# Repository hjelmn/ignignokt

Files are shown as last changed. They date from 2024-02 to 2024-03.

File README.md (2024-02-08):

This project contains all the files from my recreation of the Ignignokt LED sign. Included in this repository are the current Kicad files.

The board is roughly based on the data available at:

https://hackaday.io/project/183827-reverse-engineering-the-mooninite-led-panels/details

with minor modifications (there could be errors-- if you find some please post a PR with the fix):

 - Added a barrel power input to support an external power supply. Added a circuit to disable the batter if an external power supply is connected. This circuit uses a P-channel MOSFET which closes the Batt+ when a voltage is detected on Vcc.
 - Added a battery pack connector and pads to solder on a battery.

TODO:

 - Code for the microcontroller.
 - Err

The current version of the board costs roughly $85 to produce with LEDs from China and parts sourced from the US.

To use this project download kicad and open the project.

The license for all of these files is GPLv3.

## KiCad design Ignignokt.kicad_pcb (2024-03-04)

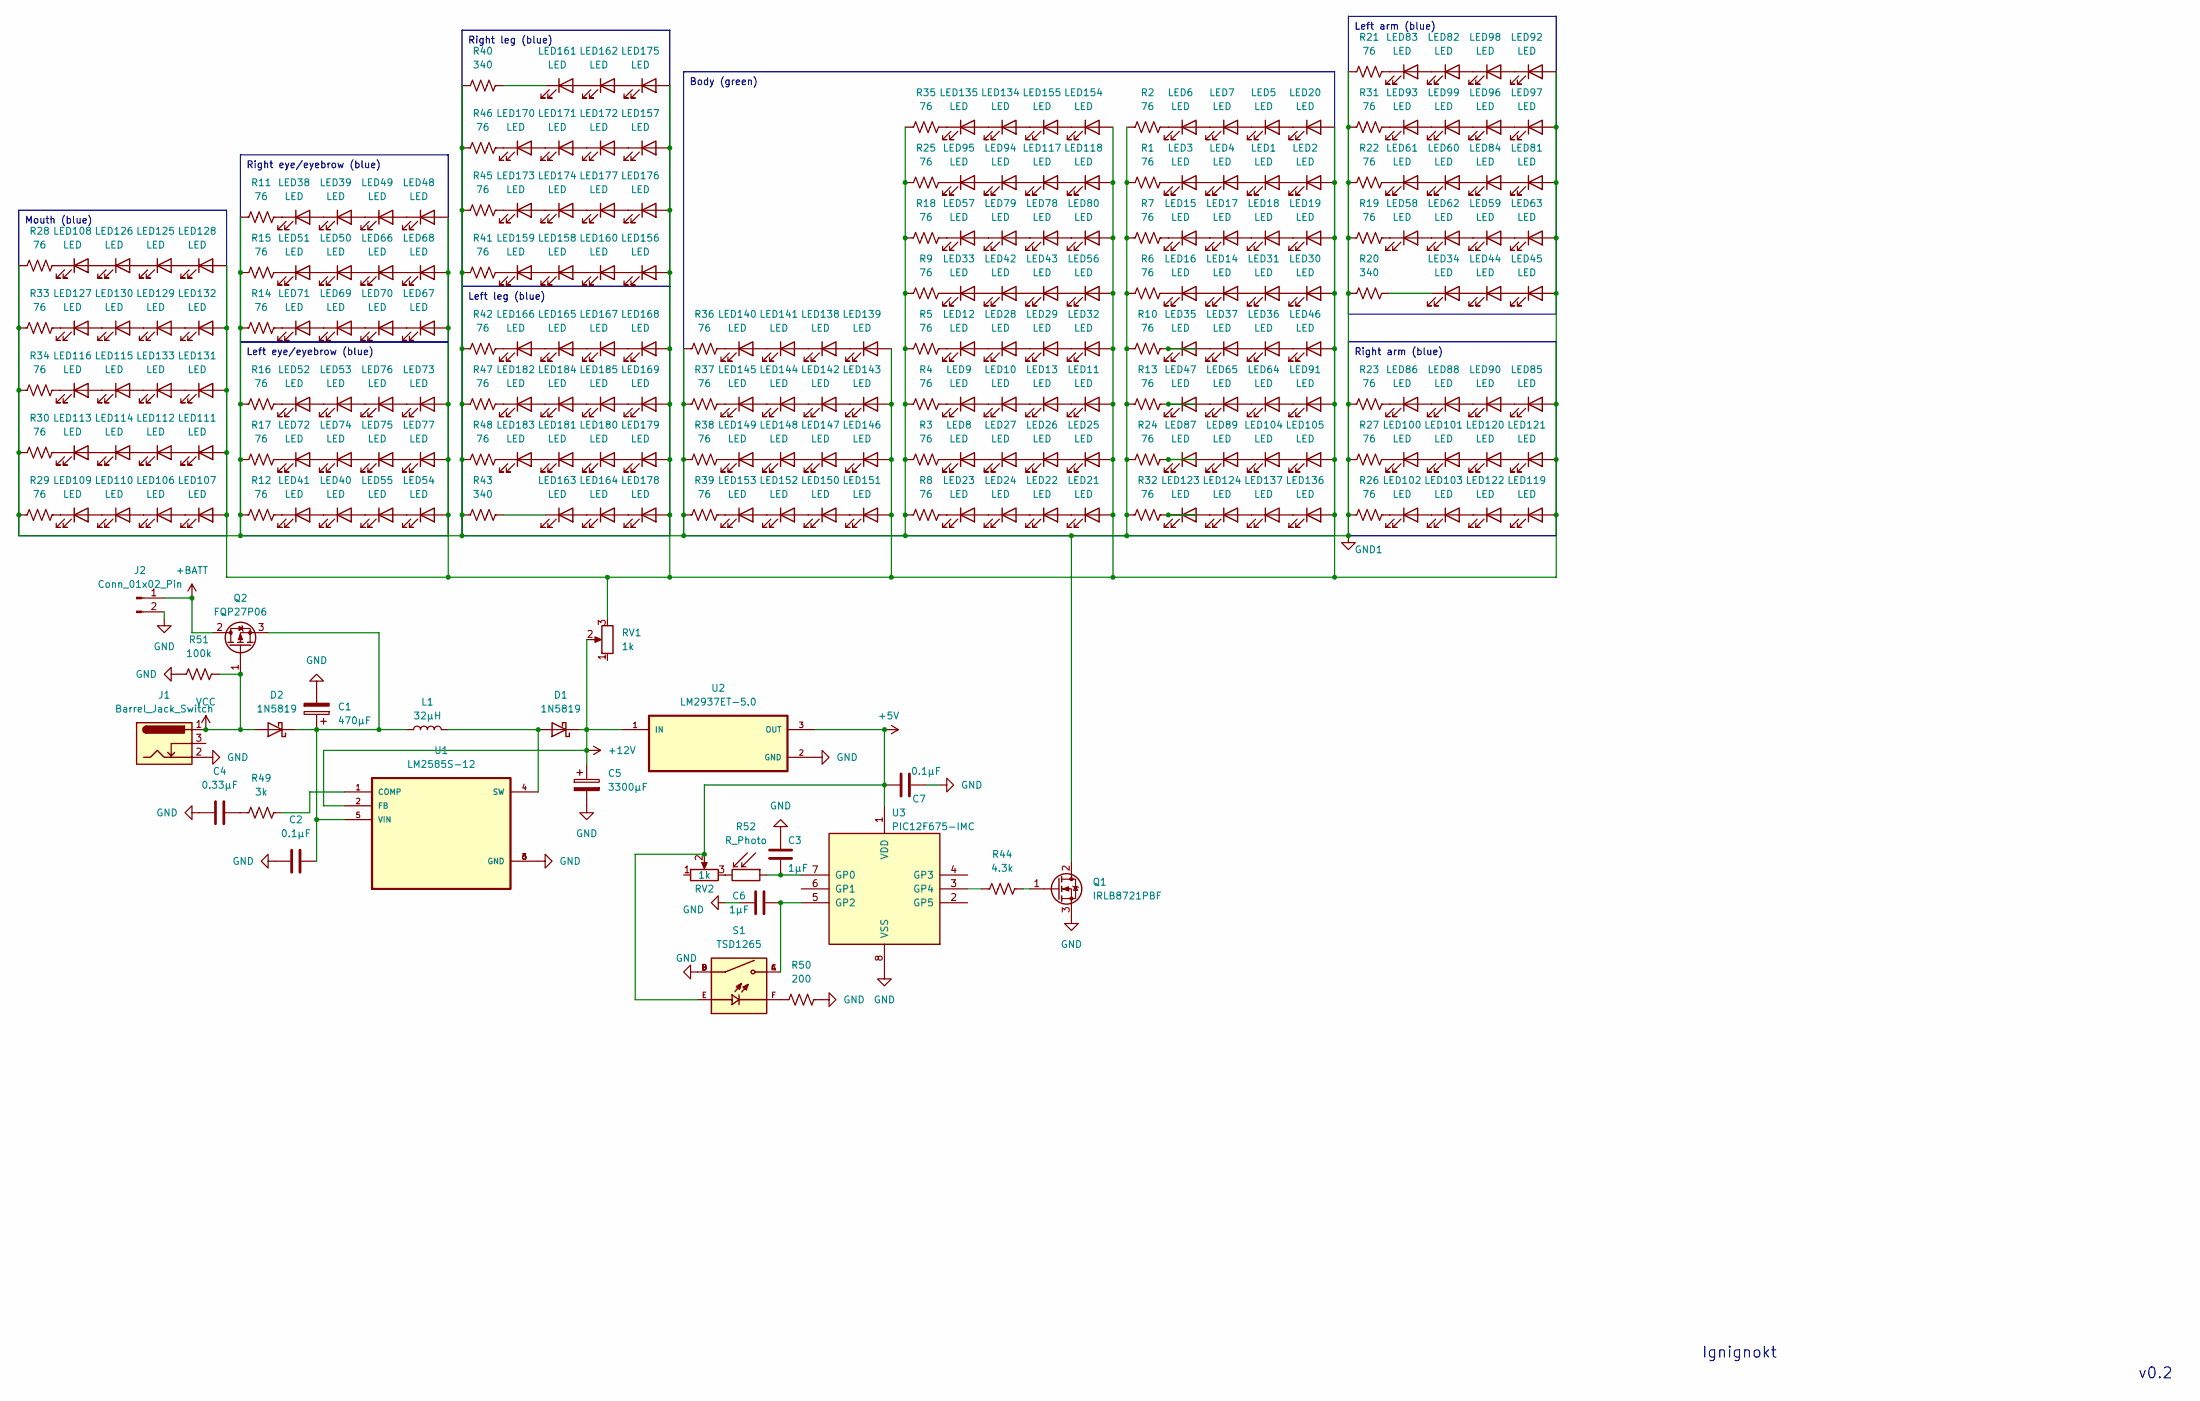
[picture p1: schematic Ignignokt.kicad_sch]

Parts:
C1: 470µF; CP_Radial_D10.0mm_P5.00mm
C2, C7: 0.1µF; C_Disc_D3.0mm_W2.0mm_P2.50mm
C3, C6: 1µF; C_Disc_D5.1mm_W3.2mm_P5.00mm
C4: 0.33µF; C_Disc_D5.1mm_W3.2mm_P5.00mm
C5: 3300µF; CP_Radial_D18.0mm_P7.50mm
D1, D2: 1N5819; D_DO-41_SOD81_P10.16mm_Horizontal
J1: Barrel_Jack_Switch; BarrelJack_Wuerth_6941xx301002
J2: Conn_01x02_Pin; JST_EH_B2B-EH-A_1x02_P2.50mm_Vertical
L1: 32µH; L_CommonMode_Toroid_Vertical_L24.0mm_W16.3mm_Px10.16mm_Py20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
LED1, LED2, LED3, LED4, LED5, LED6, LED7, LED8, LED9, LED10, LED11, LED12, LED13, LED14, LED15, LED16, LED17, LED18, LED19, LED20, LED21, LED22, LED23, LED24, LED25, LED26, LED27, LED28, LED29, LED30, LED31, LED32, LED33, LED34, LED35, LED36, LED37, LED38, LED39, LED40, LED41, LED42, LED43, LED44, LED45, LED46, LED47, LED48, LED49, LED50, LED51, LED52, LED53, LED54, LED55, LED56, LED57, LED58, LED59, LED60, LED61, LED62, LED63, LED64, LED65, LED66, LED67, LED68, LED69, LED70, LED71, LED72, LED73, LED74, LED75, LED76, LED77, LED78, LED79, LED80, LED81, LED82, LED83, LED84, LED85, LED86, LED87, LED88, LED89, LED90, LED91, LED92, LED93, LED94, LED95, LED96, LED97, LED98, LED99, LED100, LED101, LED102, LED103, LED104, LED105, LED106, LED107, LED108, LED109, LED110, LED111, LED112, LED113, LED114, LED115, LED116, LED117, LED118, LED119, LED120, LED121, LED122, LED123, LED124, LED125, LED126, LED127, LED128, LED129, LED130, LED131, LED132, LED133, LED134, LED135, LED136, LED137, LED138, LED139, LED140, LED141, LED142, LED143, LED144, LED145, LED146, LED147, LED148, LED149, LED150, LED151, LED152, LED153, LED154, LED155, LED156, LED157, LED158, LED159, LED160, LED161, LED162, LED163, LED164, LED165, LED166, LED167, LED168, LED169, LED170, LED171, LED172, LED173, LED174, LED175, LED176, LED177, LED178, LED179, LED180, LED181, LED182, LED183, LED184, LED185: LED; LED_D10.0mm
Q1: IRLB8721PBF; TO-220-3_Horizontal_TabDown
Q2: FQP27P06; TO-220-3_Horizontal_TabDown
R1, R2, R3, R4, R5, R6, R7, R8, R9, R10, R11, R12, R13, R14, R15, R16, R17, R18, R19, R21, R22, R23, R24, R25, R26, R27, R28, R29, R30, R31, R32, R33, R34, R35, R36, R37, R38, R39, R41, R42, R45, R46, R47, R48: 76; R_Axial_DIN0207_L6.3mm_D2.5mm_P10.16mm_Horizontal
R20, R40, R43: 340; R_Axial_DIN0207_L6.3mm_D2.5mm_P10.16mm_Horizontal
R44: 4.3k; R_Axial_DIN0207_L6.3mm_D2.5mm_P10.16mm_Horizontal
R49: 3k; R_Axial_DIN0207_L6.3mm_D2.5mm_P10.16mm_Horizontal
R50: 200; R_Axial_DIN0207_L6.3mm_D2.5mm_P10.16mm_Horizontal
R51: 100k; R_Axial_DIN0207_L6.3mm_D2.5mm_P10.16mm_Horizontal
R52: R_Photo; R_LDR_D6.4mm_P3.4mm_Vertical
RV1, RV2: 1k; Potentiometer_Bourns_3299W_Vertical; Part 3299W-1-103LF
S1: TSD1265; SW_TSD1265; PARTREV N/A
U1: LM2585S-12; VREG_TPS79625KTTR - LM2585S-12
U2: LM2937ET-5.0; TO-220-3_Horizontal_TabDown
U3: PIC12F675-IMC; DIP-8_W7.62mm

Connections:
+5V: C7.2, RV2.2, S1.E, U2.3 (OUT), U3.1 (VDD)
+12V: C5.1, D1.1 (K), RV1.2, U1.2 (FB), U2.1 (IN)
+BATT: J2.1, Q2.2 (D)
GND: C1.2, C2.2, C3.1, C4.2, C5.2, C6.2, C7.1, J1.2, J2.2, Q1.3 (S), R50.1, R51.2, S1.B, S1.D, U1.3 (GND), U1.6 (GND), U2.2 (GND), U3.8 (VSS)
GND1: Q1.2 (D), R1.2, R2.2, R3.2, R4.2, R5.2, R6.2, R7.2, R8.2, R9.2, R10.2, R11.2, R12.2, R13.2, R14.2, R15.2, R16.2, R17.2, R18.2, R19.2, R20.2, R21.2, R22.2, R23.2, R24.2, R25.2, R26.2, R27.2, R28.2, R29.2, R30.2, R31.2, R32.2, R33.2, R34.2, R35.2, R36.2, R37.2, R38.2, R39.2, R40.2, R41.2, R42.2, R43.2, R45.2, R46.2, R47.2, R48.2
unnamed: C4.1, R49.2
unnamed: D1.2 (A), L1.2, U1.4 (SW)
unnamed: C1.1, C2.1, D2.1 (K), L1.1, Q2.3 (S), U1.5 (VIN)
unnamed: LED1.2 (A), LED2.1 (K)
unnamed: LED1.1 (K), LED4.2 (A)
unnamed: LED3.2 (A), LED4.1 (K)
unnamed: LED3.1 (K), R1.1
unnamed: LED5.1 (K), LED7.2 (A)
unnamed: LED6.2 (A), LED7.1 (K)
unnamed: LED6.1 (K), R2.1
unnamed: LED8.1 (K), R3.1
unnamed: LED9.1 (K), R4.1
unnamed: LED10.2 (A), LED13.1 (K)
unnamed: LED9.2 (A), LED10.1 (K)
unnamed: LED11.1 (K), LED13.2 (A)
unnamed: LED12.2 (A), LED28.1 (K)
unnamed: LED12.1 (K), R5.1
unnamed: LED14.2 (A), LED31.1 (K)
unnamed: LED14.1 (K), LED16.2 (A)
unnamed: LED15.2 (A), LED17.1 (K)
unnamed: LED15.1 (K), R7.1
unnamed: LED16.1 (K), R6.1
unnamed: LED17.2 (A), LED18.1 (K)
unnamed: LED18.2 (A), LED19.1 (K)
unnamed: LED5.2 (A), LED20.1 (K)
unnamed: LED21.1 (K), LED22.2 (A)
unnamed: LED22.1 (K), LED24.2 (A)
unnamed: LED23.2 (A), LED24.1 (K)
unnamed: LED23.1 (K), R8.1
unnamed: LED25.1 (K), LED26.2 (A)
unnamed: LED26.1 (K), LED27.2 (A)
unnamed: LED8.2 (A), LED27.1 (K)
unnamed: LED28.2 (A), LED29.1 (K)
unnamed: LED29.2 (A), LED32.1 (K)
unnamed: LED30.1 (K), LED31.2 (A)
unnamed: LED33.2 (A), LED42.1 (K)
unnamed: LED33.1 (K), R9.1
unnamed: LED34.2 (A), LED44.1 (K)
unnamed: LED34.1 (K), R20.1
unnamed: LED35.2 (A), LED37.1 (K)
unnamed: LED35.1 (K), R10.1
unnamed: LED36.2 (A), LED46.1 (K)
unnamed: LED36.1 (K), LED37.2 (A)
unnamed: LED38.2 (A), LED39.1 (K)
unnamed: LED38.1 (K), R11.1
unnamed: LED39.2 (A), LED49.1 (K)
unnamed: LED40.2 (A), LED55.1 (K)
unnamed: LED40.1 (K), LED41.2 (A)
unnamed: LED41.1 (K), R12.1
unnamed: LED42.2 (A), LED43.1 (K)
unnamed: LED43.2 (A), LED56.1 (K)
unnamed: LED44.2 (A), LED45.1 (K)
unnamed: LED47.2 (A), LED65.1 (K)
unnamed: LED47.1 (K), R13.1
unnamed: LED48.1 (K), LED49.2 (A)
unnamed: LED50.2 (A), LED66.1 (K)
unnamed: LED50.1 (K), LED51.2 (A)
unnamed: LED51.1 (K), R15.1
unnamed: LED52.2 (A), LED53.1 (K)
unnamed: LED52.1 (K), R16.1
unnamed: LED53.2 (A), LED76.1 (K)
unnamed: LED54.1 (K), LED55.2 (A)
unnamed: LED57.2 (A), LED79.1 (K)
unnamed: LED57.1 (K), R18.1
unnamed: LED58.2 (A), LED62.1 (K)
unnamed: LED58.1 (K), R19.1
unnamed: LED59.2 (A), LED63.1 (K)
unnamed: LED59.1 (K), LED62.2 (A)
unnamed: LED60.2 (A), LED84.1 (K)
unnamed: LED60.1 (K), LED61.2 (A)
unnamed: LED61.1 (K), R22.1
unnamed: LED64.2 (A), LED91.1 (K)
unnamed: LED64.1 (K), LED65.2 (A)
unnamed: LED66.2 (A), LED68.1 (K)
unnamed: LED67.1 (K), LED70.2 (A)
unnamed: LED69.2 (A), LED70.1 (K)
unnamed: LED69.1 (K), LED71.2 (A)
unnamed: LED71.1 (K), R14.1
unnamed: LED72.2 (A), LED74.1 (K)
unnamed: LED72.1 (K), R17.1
unnamed: LED73.1 (K), LED76.2 (A)
unnamed: LED74.2 (A), LED75.1 (K)
unnamed: LED75.2 (A), LED77.1 (K)
unnamed: LED78.2 (A), LED80.1 (K)
unnamed: LED78.1 (K), LED79.2 (A)
unnamed: LED81.1 (K), LED84.2 (A)
unnamed: LED82.2 (A), LED98.1 (K)
unnamed: LED82.1 (K), LED83.2 (A)
unnamed: LED83.1 (K), R21.1
unnamed: LED85.1 (K), LED90.2 (A)
unnamed: LED86.2 (A), LED88.1 (K)
unnamed: LED86.1 (K), R23.1
unnamed: LED87.2 (A), LED89.1 (K)
unnamed: LED87.1 (K), R24.1
unnamed: LED88.2 (A), LED90.1 (K)
unnamed: LED92.1 (K), LED98.2 (A)
unnamed: LED93.2 (A), LED99.1 (K)
unnamed: LED93.1 (K), R31.1
unnamed: LED94.1 (K), LED95.2 (A)
unnamed: LED95.1 (K), R25.1
unnamed: LED96.2 (A), LED97.1 (K)
unnamed: LED96.1 (K), LED99.2 (A)
unnamed: LED100.2 (A), LED101.1 (K)
unnamed: LED100.1 (K), R27.1
unnamed: LED101.2 (A), LED120.1 (K)
unnamed: LED102.2 (A), LED103.1 (K)
unnamed: LED102.1 (K), R26.1
unnamed: LED103.2 (A), LED122.1 (K)
unnamed: LED104.2 (A), LED105.1 (K)
unnamed: LED89.2 (A), LED104.1 (K)
unnamed: LED2.2 (A), LED11.2 (A), LED19.2 (A), LED20.2 (A), LED21.2 (A), LED25.2 (A), LED30.2 (A), LED32.2 (A), LED45.2 (A), LED46.2 (A), LED48.2 (A), LED54.2 (A), LED56.2 (A), LED63.2 (A), LED67.2 (A), LED68.2 (A), LED73.2 (A), LED77.2 (A), LED80.2 (A), LED81.2 (A), LED85.2 (A), LED91.2 (A), LED92.2 (A), LED97.2 (A), LED105.2 (A), LED107.2 (A), LED111.2 (A), LED118.2 (A), LED119.2 (A), LED121.2 (A), LED128.2 (A), LED131.2 (A), LED132.2 (A), LED136.2 (A), LED139.2 (A), LED143.2 (A), LED146.2 (A), LED151.2 (A), LED154.2 (A), LED156.2 (A), LED157.2 (A), LED168.2 (A), LED169.2 (A), LED175.2 (A), LED176.2 (A), LED178.2 (A), LED179.2 (A), RV1.3
unnamed: LED106.2 (A), LED107.1 (K)
unnamed: LED106.1 (K), LED110.2 (A)
unnamed: LED108.2 (A), LED126.1 (K)
unnamed: LED108.1 (K), R28.1
unnamed: LED109.2 (A), LED110.1 (K)
unnamed: LED109.1 (K), R29.1
unnamed: LED111.1 (K), LED112.2 (A)
unnamed: LED112.1 (K), LED114.2 (A)
unnamed: LED113.2 (A), LED114.1 (K)
unnamed: LED113.1 (K), R30.1
unnamed: LED115.2 (A), LED133.1 (K)
unnamed: LED115.1 (K), LED116.2 (A)
unnamed: LED116.1 (K), R34.1
unnamed: LED117.2 (A), LED118.1 (K)
unnamed: LED94.2 (A), LED117.1 (K)
unnamed: LED119.1 (K), LED122.2 (A)
unnamed: LED120.2 (A), LED121.1 (K)
unnamed: LED123.2 (A), LED124.1 (K)
unnamed: LED123.1 (K), R32.1
unnamed: LED124.2 (A), LED137.1 (K)
unnamed: LED125.2 (A), LED128.1 (K)
unnamed: LED125.1 (K), LED126.2 (A)
unnamed: LED127.2 (A), LED130.1 (K)
unnamed: LED127.1 (K), R33.1
unnamed: LED129.2 (A), LED132.1 (K)
unnamed: LED129.1 (K), LED130.2 (A)
unnamed: LED131.1 (K), LED133.2 (A)
unnamed: LED134.2 (A), LED155.1 (K)
unnamed: LED134.1 (K), LED135.2 (A)
unnamed: LED135.1 (K), R35.1
unnamed: LED136.1 (K), LED137.2 (A)
unnamed: LED138.2 (A), LED139.1 (K)
unnamed: LED138.1 (K), LED141.2 (A)
unnamed: LED140.2 (A), LED141.1 (K)
unnamed: LED140.1 (K), R36.1
unnamed: LED142.2 (A), LED143.1 (K)
unnamed: LED142.1 (K), LED144.2 (A)
unnamed: LED144.1 (K), LED145.2 (A)
unnamed: LED145.1 (K), R37.1
unnamed: LED146.1 (K), LED147.2 (A)
unnamed: LED147.1 (K), LED148.2 (A)
unnamed: LED148.1 (K), LED149.2 (A)
unnamed: LED149.1 (K), R38.1
unnamed: LED150.2 (A), LED151.1 (K)
unnamed: LED150.1 (K), LED152.2 (A)
unnamed: LED152.1 (K), LED153.2 (A)
unnamed: LED153.1 (K), R39.1
unnamed: LED154.1 (K), LED155.2 (A)
unnamed: LED156.1 (K), LED160.2 (A)
unnamed: LED157.1 (K), LED172.2 (A)
unnamed: LED158.2 (A), LED160.1 (K)
unnamed: LED158.1 (K), LED159.2 (A)
unnamed: LED159.1 (K), R41.1
unnamed: LED161.2 (A), LED162.1 (K)
unnamed: LED161.1 (K), R40.1
unnamed: LED162.2 (A), LED175.1 (K)
unnamed: LED163.2 (A), LED164.1 (K)
unnamed: LED163.1 (K), R43.1
unnamed: LED164.2 (A), LED178.1 (K)
unnamed: LED165.2 (A), LED167.1 (K)
unnamed: LED165.1 (K), LED166.2 (A)
unnamed: LED166.1 (K), R42.1
unnamed: LED167.2 (A), LED168.1 (K)
unnamed: LED169.1 (K), LED185.2 (A)
unnamed: LED170.2 (A), LED171.1 (K)
unnamed: LED170.1 (K), R46.1
unnamed: LED171.2 (A), LED172.1 (K)
unnamed: LED173.2 (A), LED174.1 (K)
unnamed: LED173.1 (K), R45.1
unnamed: LED174.2 (A), LED177.1 (K)
unnamed: LED176.1 (K), LED177.2 (A)
unnamed: LED179.1 (K), LED180.2 (A)
unnamed: LED180.1 (K), LED181.2 (A)
unnamed: LED181.1 (K), LED183.2 (A)
unnamed: LED182.2 (A), LED184.1 (K)
unnamed: LED182.1 (K), R47.1
unnamed: LED183.1 (K), R48.1
unnamed: LED184.2 (A), LED185.1 (K)
unnamed: Q1.1 (G), R44.1
unnamed: R50.2, S1.F
unnamed: R52.2, RV2.3
unnamed: R49.1, U1.1 (COMP)
unnamed: C3.2, R52.1, U3.7 (GP0)
unnamed: C6.1, S1.A, S1.C, U3.5 (GP2)
unnamed: R44.2, U3.3 (GP4)
VCC: D2.2 (A), J1.1, Q2.1 (G), R51.1

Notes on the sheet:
Body (green)
Left eye/eyebrow (blue)
Left leg (blue)
Right eye/eyebrow (blue)
Right leg (blue)
Left arm (blue)
Mouth (blue)
Right arm (blue)
v0.2
Ignignokt

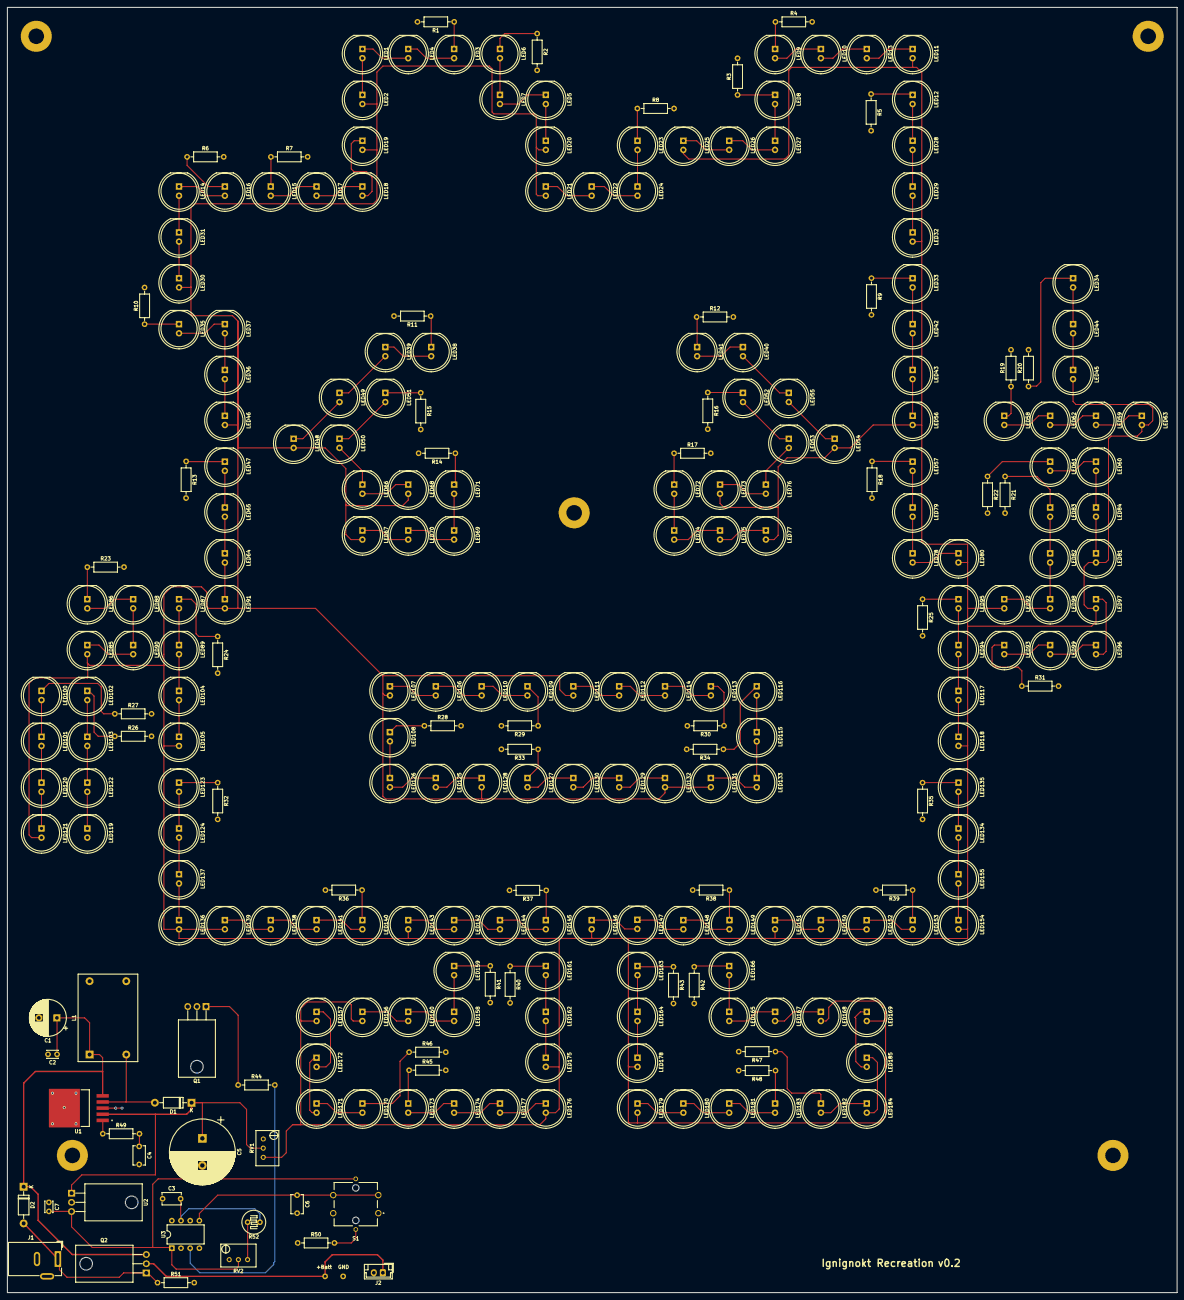
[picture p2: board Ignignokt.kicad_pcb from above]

Board: 2 copper layers, 324.0 x 356.0 mm, 257 parts (0 on the bottom side), 202 nets.

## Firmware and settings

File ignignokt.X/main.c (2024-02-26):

/* 
 * File:   main.c
 * Author: hjelmn
 *
 * (c) 2024      Nathan Hjelm <hjelmn@mac.com>
 *
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
 * Created on February 25, 2024, 8:53 AM
 */

// CONFIG
#pragma config FOSC = INTRCIO   // Oscillator Selection bits (INTOSC oscillator: I/O function on GP4/OSC2/CLKOUT pin, I/O function on GP5/OSC1/CLKIN)
#pragma config WDTE = OFF        // Watchdog Timer Enable bit (WDT disabled)
#pragma config PWRTE = OFF      // Power-Up Timer Enable bit (PWRT disabled)
#pragma config MCLRE = OFF      // GP3/MCLR pin function select (GP3/MCLR pin function is digital I/O, MCLR internally tied to VDD)
#pragma config BOREN = OFF       // Brown-out Detect Enable bit (BOD disabled)
#pragma config CP = OFF         // Code Protection bit (Program Memory code protection is disabled)
#pragma config CPD = OFF        // Data Code Protection bit (Data memory code protection is disabled)

#include <stdio.h>
#include <stdlib.h>
#include <xc.h>

#define _XTAL_FREQ 4000000  

/**
 * Wait for a given number of milli-seconds using busy waiting scheme.
 * @param time - time in ms to wait.
 */
#define wait_ms(time) __delay_ms(time)

/* Delay 500ms before reacting to the switch again. */
const unsigned long switch_delay = 500;

void configure_pins() {
    ANSEL = 0;
    GPIO = 0;
    nGPPU = 0;
    CMCON = 0b00000111;
    
    /* Configure the input pins. Pin 5 (GPIO 2) is connected to a switch to
     * ground and pin 7 (GPIO 0) is connected to a potentiometer and photo
     * resistor. Configure the output pin which will turn on/off the LEDs. This
     * is pin 3 (GPIO 4). */
    TRISIO = 0b00101;

    WPU = 0b0100;
}

int switch_activated() {
    if (GPIO2 == 0) {
        wait_ms(100);
        return GPIO2 == 0;
    }
    return 0;
}

void reset_photo_input() {
    /* Set the photoresistor pin to output temporarily */
    TRISIO = 0b00100;
    /* Pull to ground */
    GPIO0 = 0;
    __delay_us(2);
    /* Change back to input. */
    TRISIO = 0b00101;
}

void set_output(unsigned char value) {
    GPIO = value << 4;
}

int detect_brightness() {
    int counter = 0;
    reset_photo_input();
    while (GPIO0 == 0) {
        if (++counter == 10000) {
            return 10000;
        }
    }

    return counter;
}

/*
 * 
 */
int main(int argc, char** argv) {
    configure_pins();
    
    unsigned char toggle = 0;

    while (1) {
        if (switch_activated()) {
            toggle = toggle ? 0 : 1;
        }

        if (toggle || (detect_brightness() >= 8)) {
            set_output(1);
        } else {
            set_output(0);
        }
    }
    
    return (EXIT_SUCCESS);
}

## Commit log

2024-02-08 Initial revision (r0)
    [Ignignokt.kicad_pcb, Ignignokt.kicad_sch]
2024-02-25 Small tweaks to board
    The MOSFET for the LEDs was a TO-247 which did not match the part I had selected. Changed it to a TO-220 to match the part. Also added a pull-down resistor to the gate to ensure it turns off when there is no longer a voltage on the pin. The PIC chip will ground it but it makes sense to have the extra part in case the board is used without it.
    [Ignignokt.kicad_pcb, Ignignokt.kicad_sch]
2024-02-26 Small tweaks
    The original schematic I used to design the board erroneously used pin 4 (GPIO3) as an output pin. This will not work with a PIC2F675 as that pin is input-only. Moved the output to GPIO4 to correct the issue and adjusted some other components based on observations.
    To fix the boards I have I put a jumper between GPIO3 and GPIO4 and disabled external MCLR to avoid the output causing a reset of the chip.
    Also, can use a 200 ohm resistor in place of the potentiometer (dropped to 1k). 10k might be a bit too high but could work as well. Will do more calculations to see what is best since the 10k can only go down to 5.3k. At 200 ohm it takes about 8 clock cycles for the GPIO pin to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
    [Ignignokt.kicad_pcb, Ignignokt.kicad_sch]
2024-02-27 Update with a 4:0 LEDs:resistors ratio
    After closer inspection it seems the original sign was using a 4:1 ratio given there are 3 resistors for each eye/eyebrow (12 LEDS), 3 for the right arm (12 LEDs), etc. The LEDs I ordered also appear to be 2.6-2.9v forward voltage drop (not the 3-3.2 advetised) so it is better to do 4 LEDs to one 64 ohm resistor to get ~ 10mA of current. These LEDs are super bright so running close to 20mA would be a mistake.
    [Ignignokt.kicad_pcb, Ignignokt.kicad_sch]
2024-02-28 Small tweaks
    [Ignignokt.kicad_pcb, Ignignokt.kicad_sch]
2024-02-28 Fix a minor issue
    [Ignignokt.kicad_sch]
2024-03-03 Fix potentiometer issues
    Screwed up the schematic for the potentiometers. The middle lead should be connected to power not the right lead. No lead should be connected to ground.
    [Ignignokt.kicad_pcb, Ignignokt.kicad_sch]
2024-03-04 Some minor tweaks
    Moved the button light to between the light and ground instread of between power and the light. Cleaned up the schematic somewhat.
    [Ignignokt.kicad_pcb, Ignignokt.kicad_sch]
